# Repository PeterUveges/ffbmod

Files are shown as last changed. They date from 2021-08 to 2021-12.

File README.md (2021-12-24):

# YuSynth Fixed Filter Bank (modified)

This is a somewhat modified version of Yves Usson's [module](https://www.yusynth.net/Modular/EN/BANK/index.html) in Kosmo format. Changes are:

* Tuning.
* Addition of auxiliary PCB for board mounted slide pots and jacks (instead of Usson's panel mounted, wired rotary pots and jacks).
* Relocation of headers on main PCB to accommodate mating with sockets on panel components PCB. Ribbon cable is replaced by mated header/socket.
* Use of dual bypass caps (one from each rail to ground instead of one between the two rails).
* Omission of MOTM and MTA power headers.

## Errata

**WARNING!** On the first run PCBs (marked Aug 2021, no version number) the power connections to the ICs were reversed. To get around this, install all ICs "backwards", opposite the direction indicated on the silkscreen. The error has been corrected in the design files — by rerouting the power, not by turning the ICs — and power connections are correct on boards marked v1.0 (Oct 2021) or later. If in doubt use your multimeter before installing ICs to verify +12 V is on pin 4, -12 V is on pin 11. A good idea any time you build a module anyway, especially one with eight ICs!

## Tuning
Usson's filters are tuned to the same frequencies as in the Moog 914 module, except that for some reason he used 750 Hz instead of 700 Hz. The Moog filter frequencies are about six semitones (half an octave) apart. But note the following observation from the catalog description of the [Serge Resonant Equalizer](https://www.elby-designs.com/webtek/cgs/serge/cgs202/cgs202.htm): 

> Except for the top and bottom frequency bands, all other bands are spaced at an interval of a major seventh. This non-standard spacing avoids the very common effect of an accentuated resonance in one key, as will be the effect from graphic equalizers with octave or third-octave spacing between bands. Spacing by octaves will reinforce a regular overtone structure for one musical key, thereby producing regularly spaced formants accenting a particular tonality. The Resonant Equalizer's band spacing are much more interesting, producing formant peaks and valleys that are similar to those in acoustic instument sounds.

Following something like this idea, I have retuned Usson's module. Specifically, the first band pass is kept at 125 Hz and the other filters are tuned at six and a half semitones apart. 

For a list of the new frequencies, new capacitor values for the low pass and band pass filters, and new resistor values for the high pass filter, see [retuning.md](Docs/retuning.md).

In the tuning Usson used, all the required capacitances are non standard values, so he used pairs of standard value capacitors adding to the required value. Note that in this new tuning several of the required capacitances come out to available standard values. For those, only a single capacitor instead of two is used (saving 20 capacitors! Though this is partly offset by my use of dual bypass caps.) The unneeded capacitors are shown (marked DNF, "do not fit") in the schematic and have footprints on the PCB, in case I or anyone else ever wants to use this board for a differently-tuned version. For a build with my tuning, these footprints should be left unpopulated.

## Current draw
46 mA +12 V, 46 mA -12 V (This is what I measured; Usson says 70 mA on both rails (at ±15 V).)

## YuSynth request

Usson writes: 'All circuits, schematics, printed circuit board, panel design and associated data published on \[yusynth.net\] can be used for private use only.' I do not believe this repo violates his wishes and you are urged to respect them as well. CC0 licensing is intended to cover my modifications and original work, not to negate Usson's rights regarding his designs.

## Photos

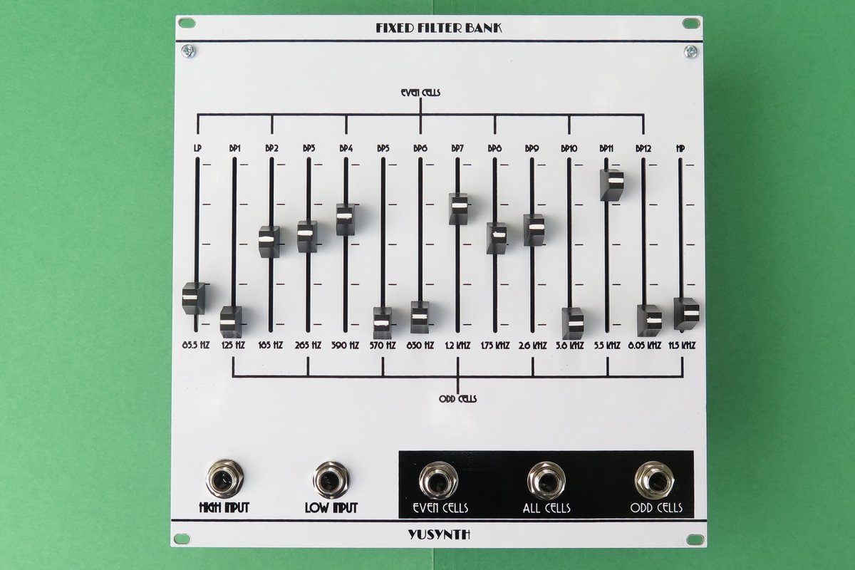
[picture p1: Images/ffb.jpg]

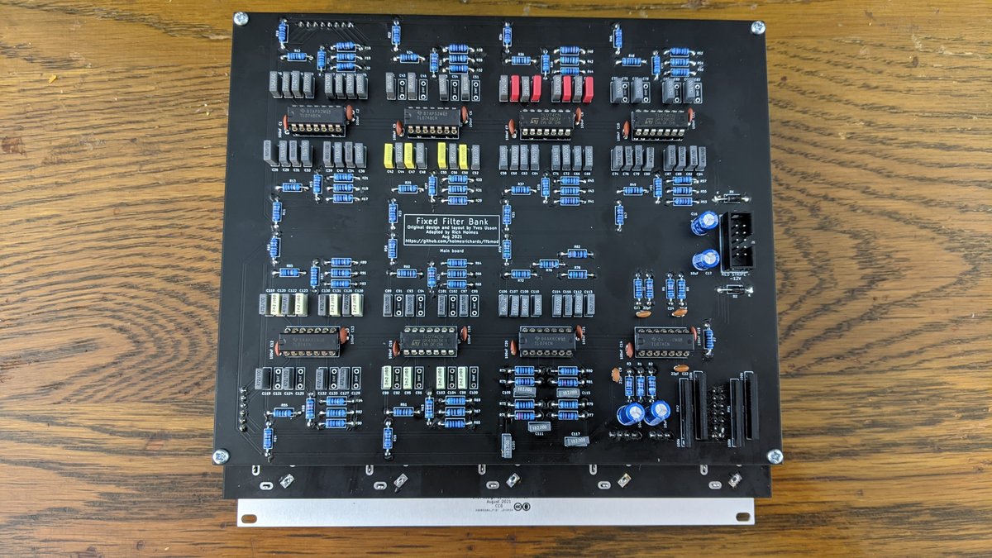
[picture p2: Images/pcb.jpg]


## Documentation:

* [Schematic](Docs/ysFFB.pdf)
* PCB layout: [front](Docs/ysFFB_layout_front.pdf), [back](Docs/ysFFB_layout_back.pdf)
* [BOM](Docs/ysFFB_bom.md)
* [Build notes](Docs/build.md)
* [Retuning](Docs/retuning.md)

## GitHub repository

* [https://github.com/holmesrichards/ffbmod](https://github.com/holmesrichards/ffbmod)

## Submodules

This repo uses submodules aoKicad and Kosmo_panel, providing libraries needed for KiCad. To clone:

```
git clone git@github.com:holmesrichards/ffb.git
git submodule init
git submodule update
```

Alternatively do

```
git clone --recurse-submodules git@github.com:holmesrichards/ffb.git
```

Or if you download the repository as a zip file, you must also click on the "aoKicad" and "Kosmo\_panel" links on the GitHub page (they'll have "@ something" after them) and download them as separate zip files which you can unzip into this repo's aoKicad and Kosmo\_panel directories.

If desired, copy the files from aoKicad and Kosmo\_panel to wherever you prefer (your KiCad user library directory, for instance, if you have one). Then in KiCad, add symbol libraries 

```
aoKicad/ao_symbols
Kosmo_panel/Kosmo
```
and footprint libraries 
```
aoKicad/ao_tht
Kosmo_panel/Kosmo_panel.
```

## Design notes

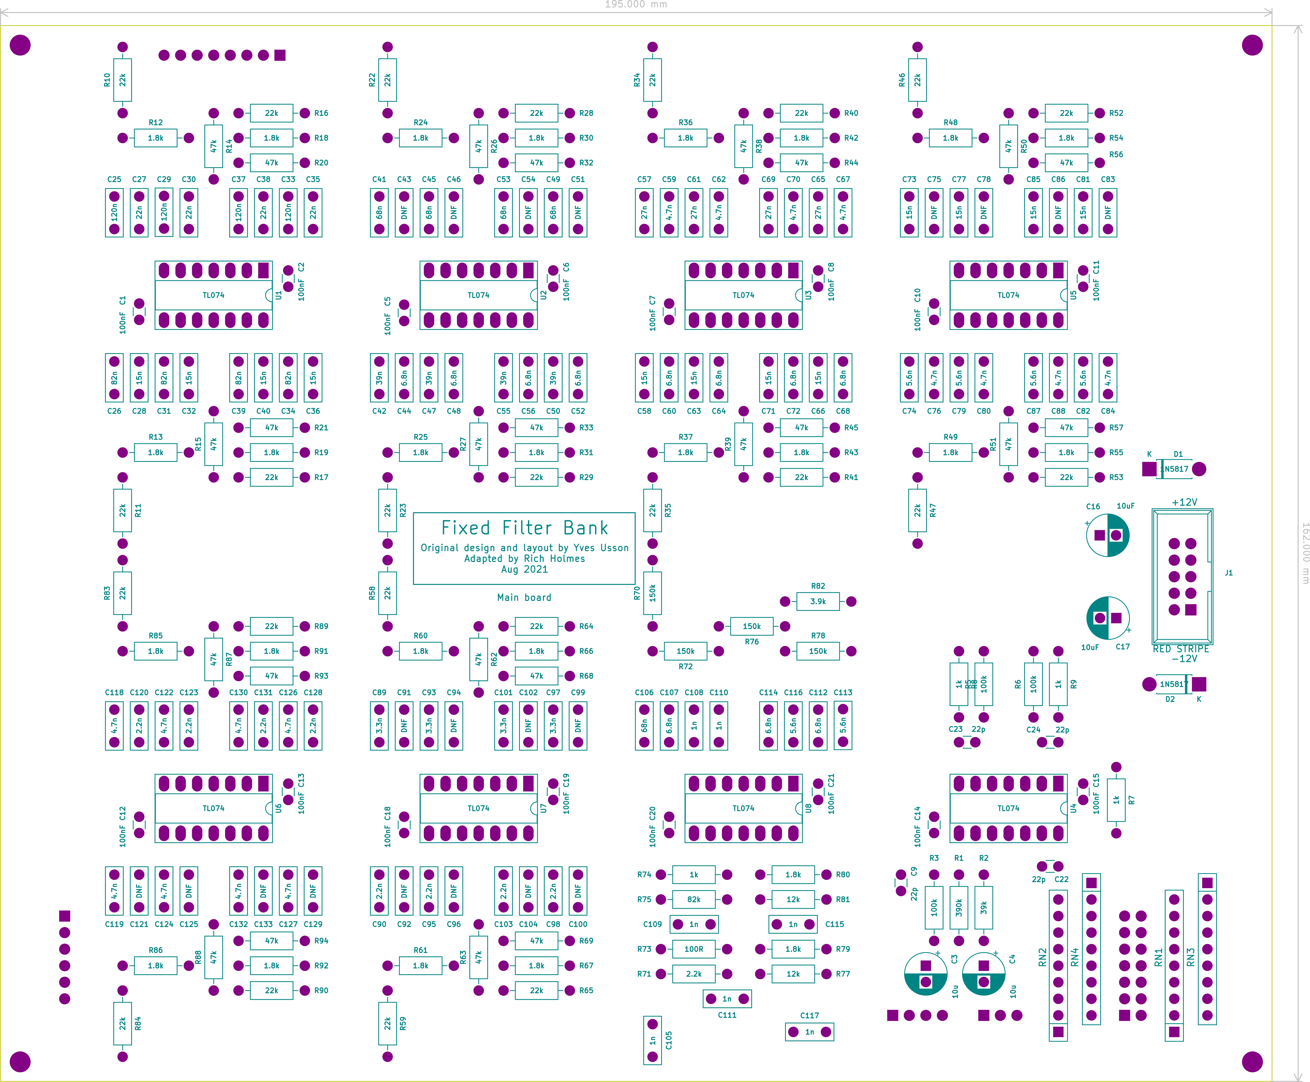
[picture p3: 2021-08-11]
Hardware/Panel/output_mb.png

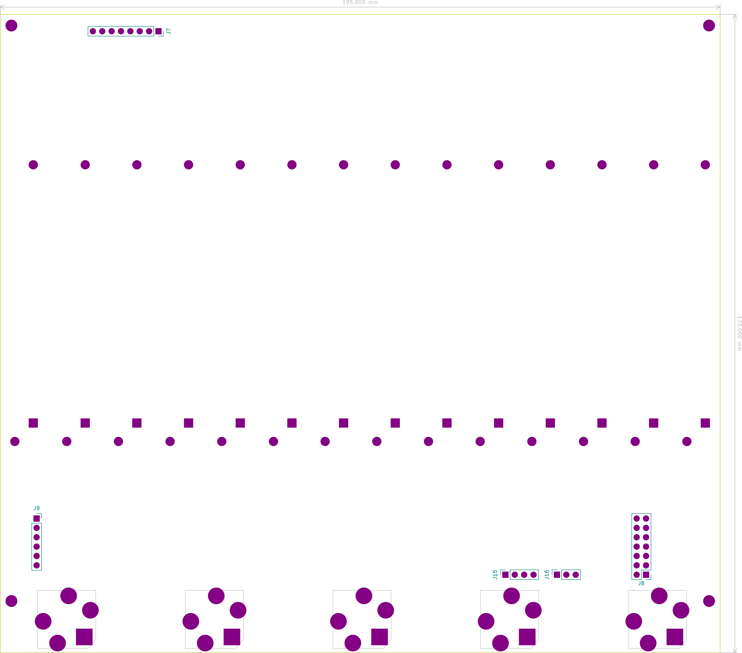
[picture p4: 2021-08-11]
Hardware/Panel/output_pb.png

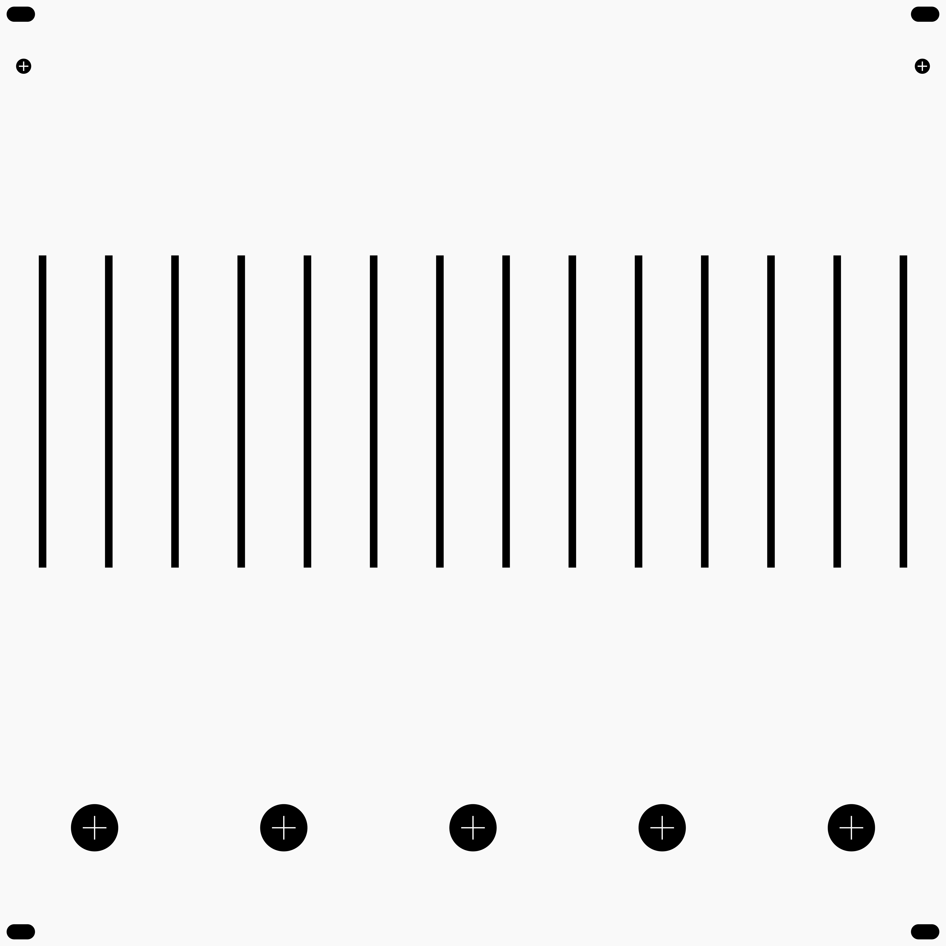
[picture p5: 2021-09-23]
Images/ysFFB-panel_slide2_holes.png

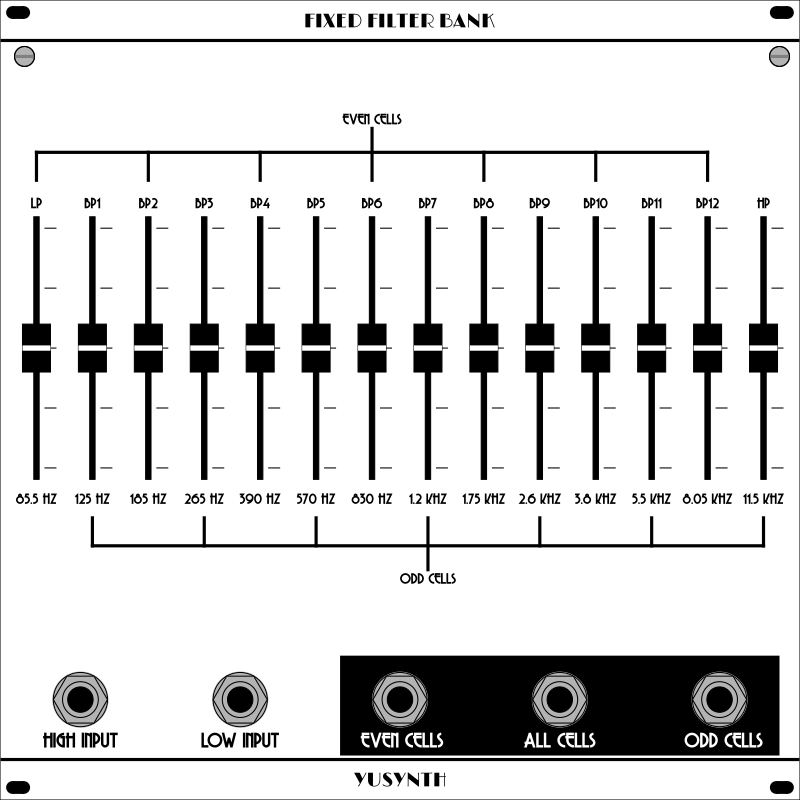
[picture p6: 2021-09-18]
Images/ysFFB-panel_slide2.png

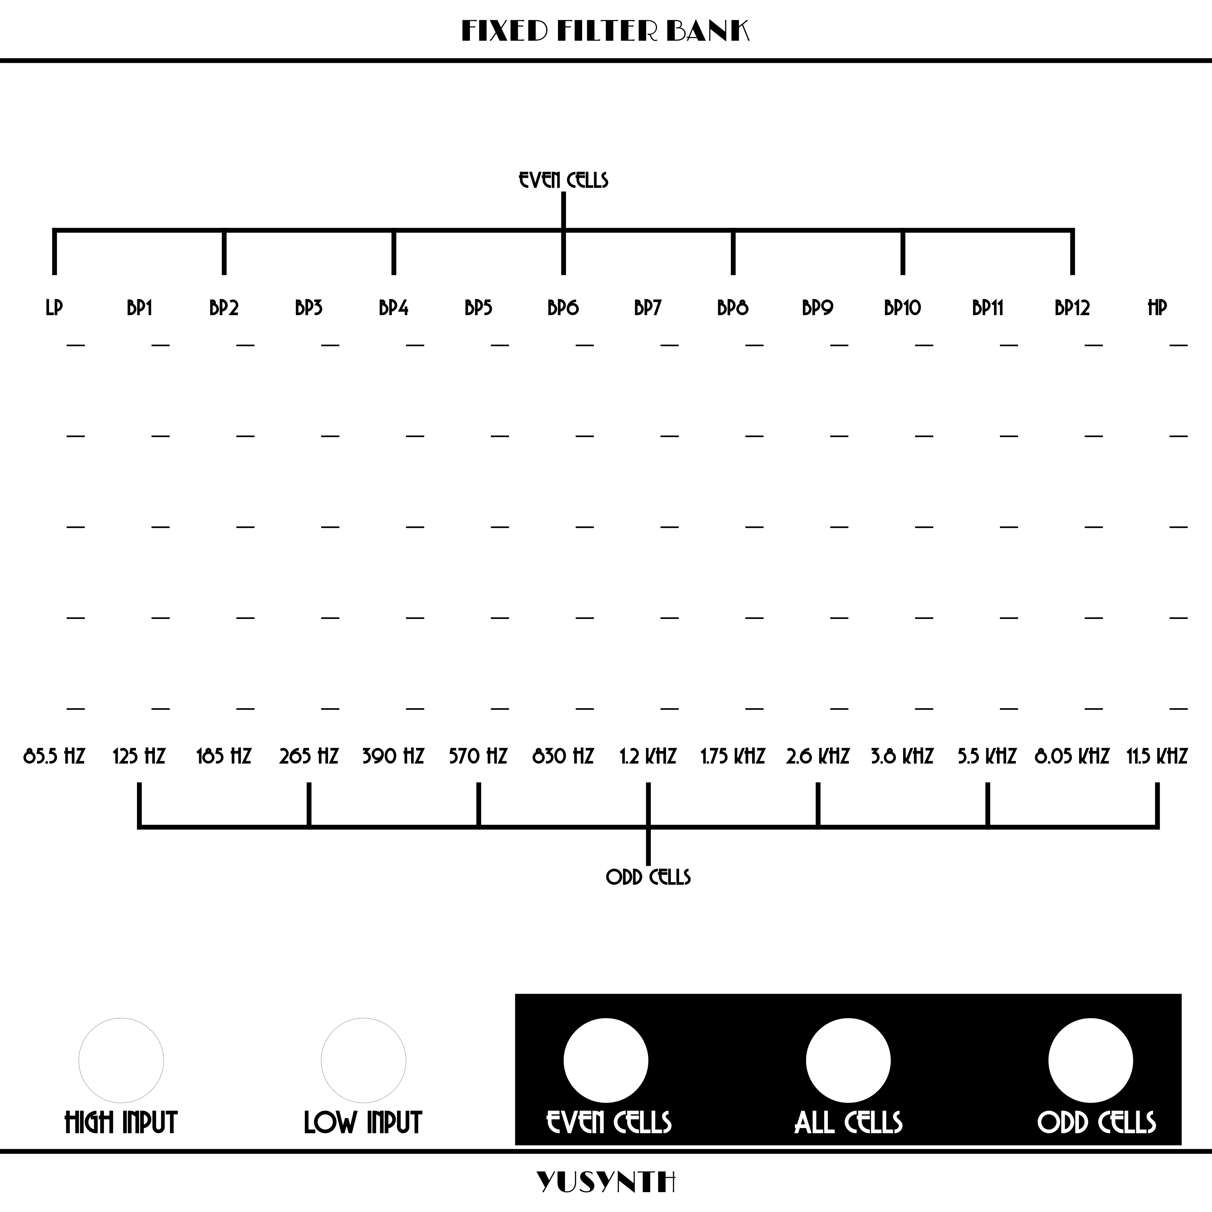
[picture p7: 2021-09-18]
Images/ysFFB-panel_slide2_art.png

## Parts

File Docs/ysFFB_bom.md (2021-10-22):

# ysFFB.sch BOM

Fri 22 Oct 2021 06:18:31 PM EDT

Generated from schematic by Eeschema 5.1.10-88a1d61d58~90~ubuntu20.04.1

**Component Count:** 270

| Refs | Qty | Component | Description | Vendor | SKU |
| ----- | --- | ---- | --- | ---- | ---- |
| C1, C2, C5, C6, C7, C8, C10, C11, C12, C13, C14, C15, C18, C19, C20, C21 | 16 | 100nF | Ceramic capacitor | Tayda | A-553 |
| C3, C4, C16, C17 | 4 | 10uF | Electrolytic capacitor | Tayda | A-4349 |
| C9, C22, C23, C24 | 4 | 22pF | Ceramic capacitor | Tayda | A-967 |
| C25, C29, C33, C37 | 4 | 120nF | Film capacitor | Tayda | A-4350 |
| C26, C31, C34, C39 | 4 | 82nF | Film capacitor | Tayda | A-279 |
| C27, C30, C35, C38 | 4 | 22nF | Film capacitor | Tayda | A-560 |
| C28, C32, C36, C40, C58, C63, C66, C71, C73, C77, C81, C85 | 12 | 15nF | Film capacitor | Tayda | A-702 |
| C41, C45, C49, C53, C106 | 5 | 68nF | Film capacitor | Tayda | A-707 |
| C42, C47, C50, C55 | 4 | 39nF | Film capacitor | Tayda | A-711 |
| C44, C48, C52, C56, C60, C64, C68, C72, C107, C112, C114 | 11 | 6.8nF | Film capacitor | Tayda | A-421 |
| C57, C61, C65, C69 | 4 | 27nF | Film capacitor | Tayda | A-562 |
| C59, C62, C67, C70, C76, C80, C84, C88, C118, C119, C122, C124, C126, C127, C130, C132 | 16 | 4.7nF | Film capacitor | Tayda | A-413 |
| C74, C79, C82, C87, C113, C116 | 6 | 5.6nF | Film capacitor | Tayda | A-423 |
| C89, C93, C97, C101 | 4 | 3.3nF | Film capacitor | Tayda | A-414 |
| C90, C95, C98, C103, C120, C123, C128, C131 | 8 | 2.2nF | Film capacitor | Tayda | A-558 |
| C105, C108, C109, C110, C111, C115, C117 | 7 | 1nF | Film capacitor | Tayda | A-557 |
| D1, D2 | 2 | 1N5817 | Schottky diode | Tayda | A-159 |
| J1 | 1 | Synth_power_2x5 | Shrouded IDC header 2.54 mm 2x5 | Tayda | A-2939 |
| J2 | 1 | Conn_01x08 | Pin header 2.54 mm 1x8 | Tayda | A-197 |
| J3 | 1 | Conn_01x06 | Pin header 2.54 mm 1x6 | Tayda | A-197 |
| J4 | 1 | Conn_01x04 | Pin header 2.54 mm 1x4 | Tayda | A-197 |
| J5 | 1 | Conn_02x07_Odd_Even | Pin header 2.54 mm 2x7 | Tayda | A-198 |
| J6 | 1 | Conn_01x03 | Pin header 2.54 mm 1x3 | Tayda | A-197 |
| J7 | 1 | Conn_01x08 | Pin socket 2.54 mm 1x8 | Tayda | A-196 |
| J8 | 1 | Conn_02x07_Odd_Even | Pin socket 2.54 mm 2x7 | Tayda | A-1696 |
| J9 | 1 | Conn_01x06 | Pin socket 2.54 mm 1x6 | Tayda | A-196 |
| J10, J11, J12, J13, J14 | 5 | AudioJack2 | Audio Jack, 2 Poles (Mono / TS) | Tayda | A-1121 |
| J15 | 1 | Conn_01x04 | Pin socket 2.54 mm 1x4 | Tayda | A-196 |
| J16 | 1 | Conn_01x03 | Pin socket 2.54 mm 1x3 | Tayda | A-196 |
| R1 | 1 | 390k | Resistor |  |  |
| R2 | 1 | 39k | Resistor |  |  |
| R3, R5, R6 | 3 | 100k | Resistor |  |  |
| R7, R8, R9, R74 | 4 | 1k | Resistor |  |  |
| R10, R11, R16, R17, R22, R23, R28, R29, R34, R35, R40, R41, R46, R47, R52, R53, R58, R59, R64, R65, R83, R84, R89, R90 | 24 | 22k | Resistor |  |  |
| R12, R13, R18, R19, R24, R25, R30, R31, R36, R37, R42, R43, R48, R49, R54, R55, R60, R61, R66, R67, R79, R80, R85, R86, R91, R92 | 26 | 1.8k | Resistor |  |  |
| R14, R15, R20, R21, R26, R27, R32, R33, R38, R39, R44, R45, R50, R51, R56, R57, R62, R63, R68, R69, R87, R88, R93, R94 | 24 | 47k | Resistor |  |  |
| R70, R72, R76, R78 | 4 | 150k | Resistor |  |  |
| R71 | 1 | 2.2k | Resistor |  |  |
| R73 | 1 | 100R | Resistor |  |  |
| R75 | 1 | 82k | Resistor |  |  |
| R77, R81 | 2 | 12k | Resistor |  |  |
| R82 | 1 | 3.9k | Resistor |  |  |
| RN1, RN2, RN3, RN4 | 4 | 100k | 8 resistor network, star topology, bussed resistors | Digi-Key | 4309R-101-104LF |
| RV1, RV2, RV3, RV4, RV5, RV6, RV7, RV8, RV9, RV10, RV11, RV12, RV13, RV14 | 14 | A10k | 60 mm slide potentiometer | Tayda | A-1617 |
| U1, U2, U3, U4, U5, U6, U7, U8 | 8 | TL074 | Quad operational amplifier, DIP-14 | Tayda | A-1138 |
| | 8 | | DIP socket 14 pin | Tayda | A-004 |
| | 6 | | M3 screw 6 mm | Tayda | A-1250 |
| | 2 | | M3 washer | Tayda | A-4389 |
| | 2 | | M3 spacer MF 22 mm | Tayda | A-1285 |
| | 4 | | M3 spacer FF 10 mm | Tayda | A-1232 |
| | 14 | | Slide pot shaft cap | AliExpress | |
    
The following references have footprints but are not populated:
C43, C46, C51, C54, C75, C78, C83, C86, C91, C92, C94, C96, C99, C100, C102, C104, C121, C125, C129, C133

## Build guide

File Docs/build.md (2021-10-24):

# Fixed filter bank build notes

This is a pretty massive module, with a 20 by 20 cm front panel, 94 fixed resistors (not counting four resistor arrays), 14 slide pots, 113 capacitors, and 8 quad op amps. But building it is very straightforward. A lot of soldering but not a lot of complications.

To repeat from the README file:

**WARNING!** On the first run PCBs (marked Aug 2021, no version number) the power connections to the ICs were reversed. To get around this, install all ICs "backwards", opposite the direction indicated on the silkscreen. The error has been corrected in the design files — by rerouting the power, not by turning the ICs — and power connections are correct on boards marked v1.0 (Oct 2021) or later. If in doubt use your multimeter before installing ICs to verify +12 V is on pin 4, -12 V is on pin 11. A good idea any time you build a module anyway, especially one with eight ICs!

Each filter has its own region on the PCB, plus a region for the input and output sections. I built mine incrementally. I did the input and output sections and one of the bandpass filters first, and tested those. Then I added the low and high pass filters, and tested again. Then I added the remaining 11 bandpass filters.

This was the first time I used SIP resistor arrays. These contain eight resistors all connected at one end to one terminal and at the other end to eight other individual terminals. The common terminal is the one on the left when the printing on the SIP is facing you, and it goes in the hole with the square pad. (Note two arrays are oriented opposite the other two.)

I recommend soldering at least the 2x7 pin header on the main PCB before the resistor arrays. But you might as well do them all. Put the pin headers and sockets together and sandwich them between the PCBs before soldering them. They all go on the sides opposite the other components. I found it easier to do the three larger headers/sockets first, then add the two smaller ones.

As usual, use the front panel to line up the pots and jacks before soldering them in place.

To assemble mechanically: Screw two 22 mm male-female spacers to the mounting holes on the front panel. Screw two 10 mm female-female spacers, with a washer added, to the bottom mounting holes on the panel components board. Secure the panel components PCB to the front panel using the jacks and by screwing two more 10 mm spacers, again with a washer added, onto the 22 mm spacers. Plug the main PCB headers into the panel components PCB sockets and secure the main PCB with four screws into the 10 mm spacers.

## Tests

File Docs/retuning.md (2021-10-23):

# YuSynth Fixed Filter Bank retuning

New frequencies and component values, computed using the formulas in Usson's writeup, are shown below. I wrote a Python script to aid in this which you can find in the Software folder. All the capacitor values are available for polyester film caps from Tayda as of April 2021. 

Note that some capacitor references are not used; the footprints are on the PCB but should be left unpopulated.

These tables were transcribed manually from the schematics. If you find any discrepancies, believe the schematics.

### Low pass
| Freq | Ref | Value | Ref | Value |
| ---- | --- | ----- | --- | ----- |
| 85.5 Hz | C106 | 68 nF | C107 | 6.8 nF |
| | C108 | 1 nF | C114 | 1 nF |
| | C112 C114 | 6.8 nF	| C113 C116 | 5.6 nF |

### Band pass
| Number | Freq | Ref | Value | Ref | Value |
| --- | ---- | --- | ----- | --- | ----- |
|1| 125 Hz | C25 C29 C33 C37 | 120 nF | C27 C30 C35 C38 | 22 nF |
|2| 185 Hz | C26 C31 C34 C39 | 82 nF | C28 C32 C36 C40 | 15 nF |
|3| 265 Hz | C41 C45  C49  C53  | 68 nF | C43 C36  C51  C54  | [unused] |
|4| 390 Hz | C42  C47  C50  C55  | 39 nF | C44  C48  C52  C56  | 6.8 nF |
|5| 570 Hz | C57  C61  C65  C69  | 27 nF | C59  C62  C67  C70  | 4.7 nF |
|6| 830 Hz | C58  C63  C66  C71  | 15 nF | C60  C64  C68  C72  | 6.8 nF |
|7| 1200 Hz | C73  C77  C81  C85  | 15 nF | C75  C78  C83  C86  | [unused] |
|8| 1750 Hz | C74  C79  C82  C87  | 5.6 nF | C76  C80  C84  C88  | 4.7 nF |
|9| 2600 Hz | C118 C122 C126 C130 | 4.7 nF | C120 C123 C128 C131 | 2.2 nF |
|10| 3800 Hz | C119 C124 C127 C132 | 4.7 nF | C121 C125 C129 C133 | [unused] |
|11| 5500 Hz | C89  C93  C97  C101 | 3.3 nF | C91  C94  C99  C104 | [unused] |
|12| 8050 Hz | C90  C95  C96  C103 | 2.2 nF | C92  C96  C100 C104 | [unused] |

### High pass
| Freq | Ref | Value | Ref | Value |
| ---- | --- | ----- | --- | ----- |
| 11500 Hz | R71  | 2.2 kΩ | R73  | 100 Ω |
|  | R75  | 82 kΩ | R74  | 1 kΩ |
|  | R77  R81  | 12 kΩ | R79  R80  | 1.8 kΩ |

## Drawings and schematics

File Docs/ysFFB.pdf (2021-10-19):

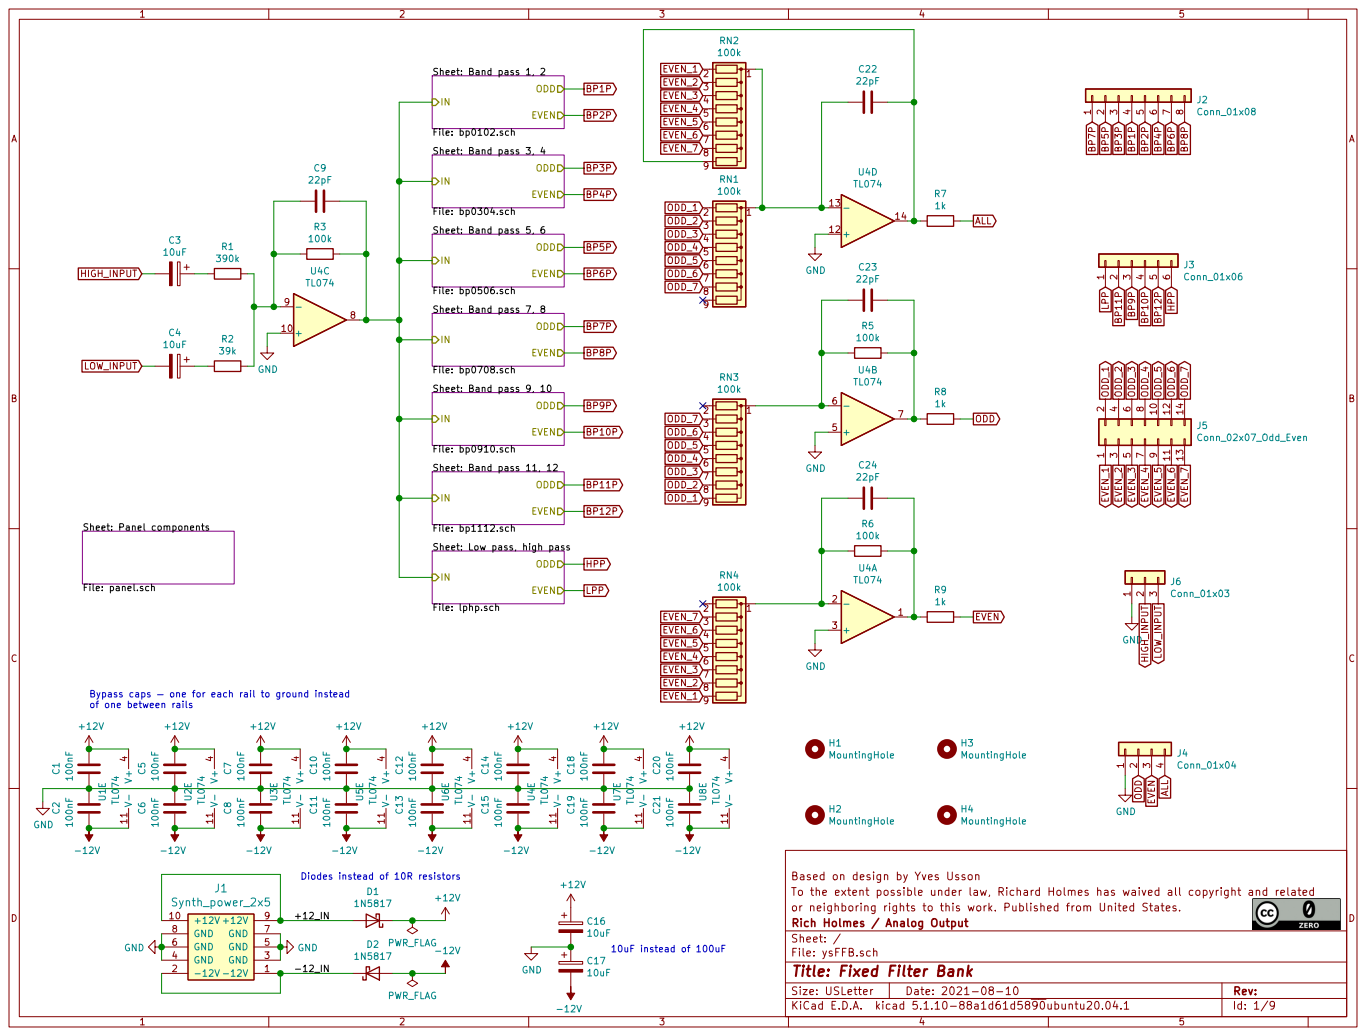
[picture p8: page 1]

Sheet: Low pass, high pass

10uF instead of 100uF Diodes instead of 10R resistors Bypass caps one for each rail to ground instead
of one between rails

Based on design by Yves Usson
To the extent possible under law, Richard Holmes has waived all copyright and related
or neighboring rights to this work. Published from United States.
File: ysFFB.sch Sheet: / Rich Holmes / Analog Output

Id: 1/9 Title: Fixed Filter Bank

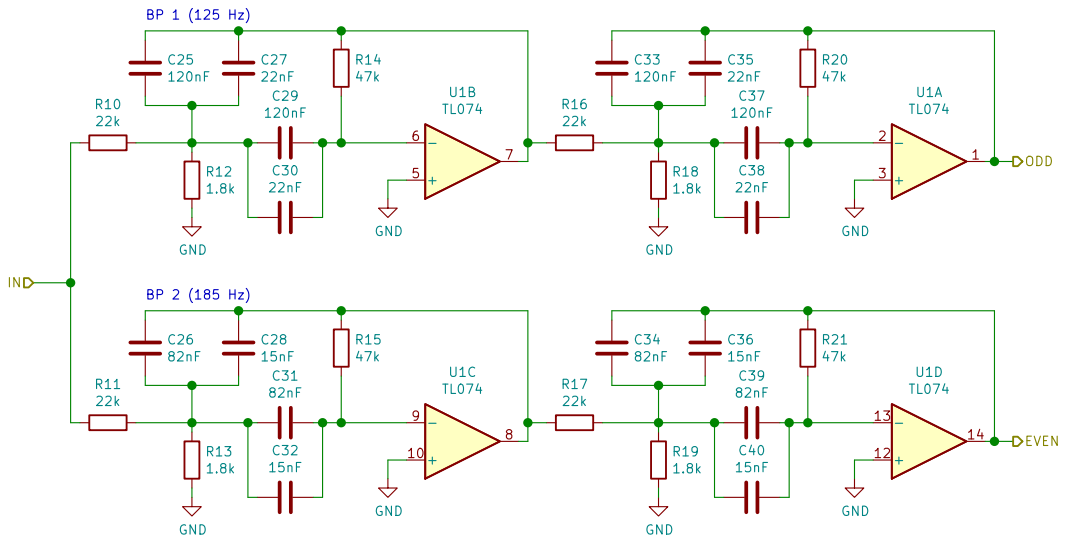
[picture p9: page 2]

Based on design by Yves Usson
To the extent possible under law, Richard Holmes has waived all copyright and related
or neighboring rights to this work. Published from United States.
Rich Holmes / Analog Output
Sheet: /Band pass 1, 2/
File: bp0102.sch
Id: 2/9 Title: Fixed Filter Bank

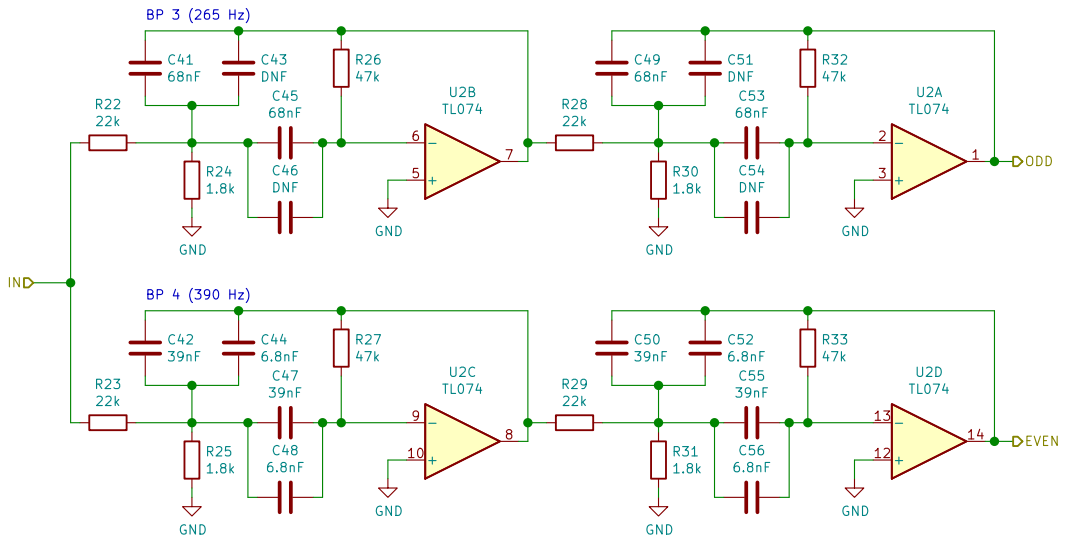
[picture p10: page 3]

Based on design by Yves Usson R25

To the extent possible under law, Richard Holmes has waived all copyright and related
or neighboring rights to this work. Published from United States.
Rich Holmes / Analog Output
Sheet: /Band pass 3, 4/
File: bp0304.sch
Id: 3/9 Title: Fixed Filter Bank

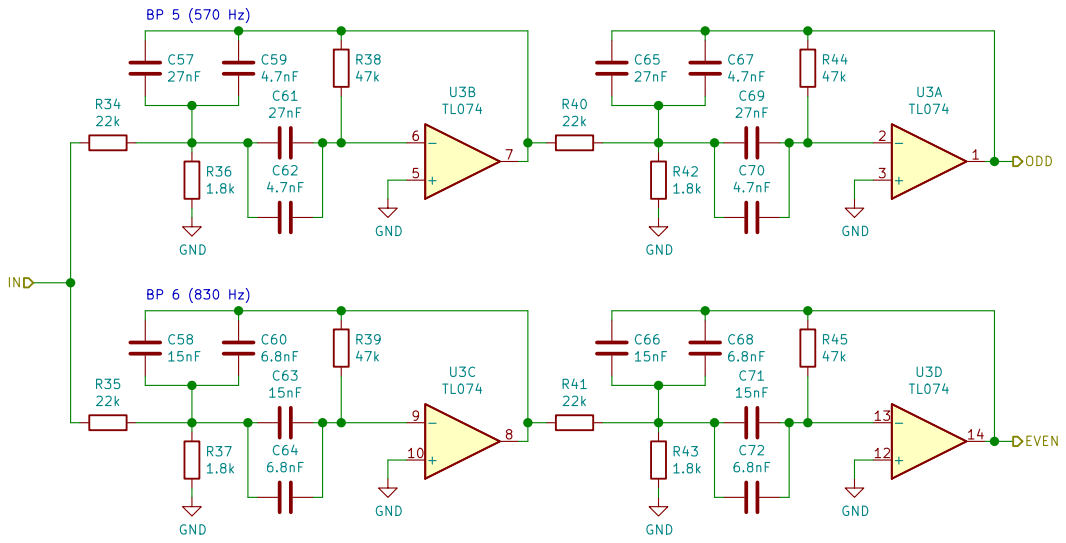
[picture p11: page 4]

Based on design by Yves Usson
To the extent possible under law, Richard Holmes has waived all copyright and related
or neighboring rights to this work. Published from United States.
Rich Holmes / Analog Output
Sheet: /Band pass 5, 6/
File: bp0506.sch
Id: 4/9 Title: Fixed Filter Bank

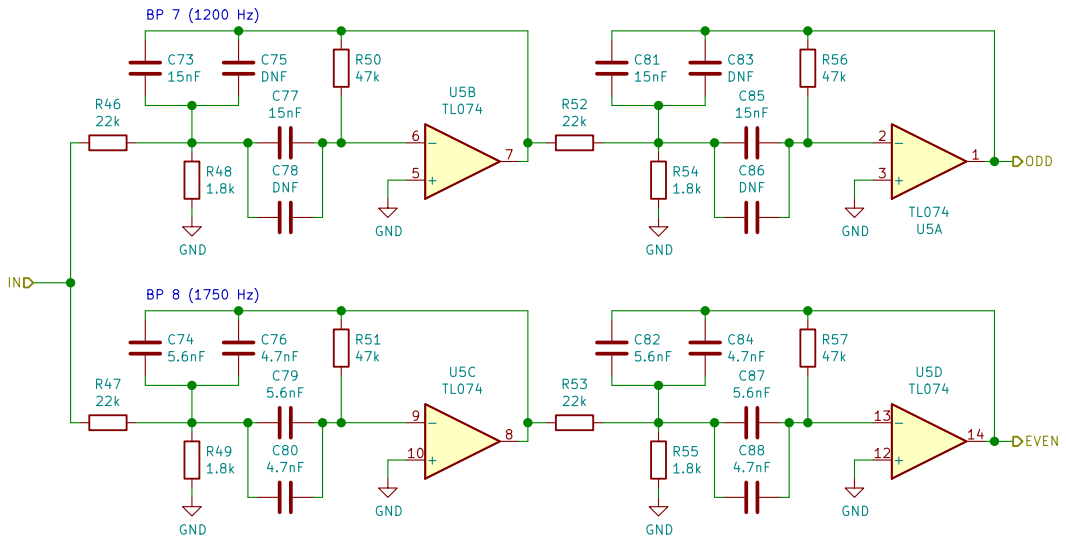
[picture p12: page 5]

Based on design by Yves Usson R49

To the extent possible under law, Richard Holmes has waived all copyright and related
or neighboring rights to this work. Published from United States.
Rich Holmes / Analog Output
Sheet: /Band pass 7, 8/
File: bp0708.sch
Id: 5/9 Title: Fixed Filter Bank

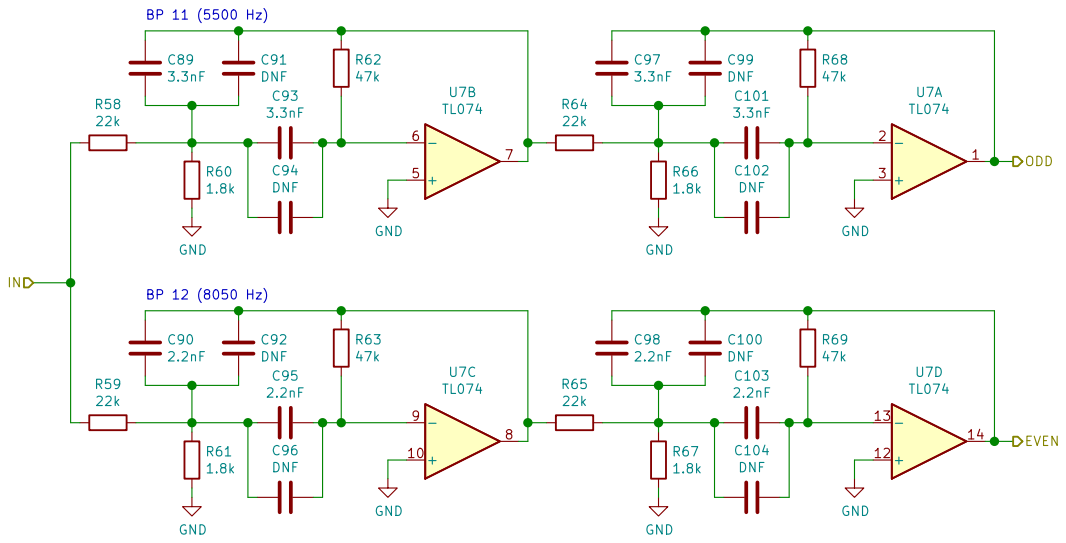
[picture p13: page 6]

Based on design by Yves Usson R61

To the extent possible under law, Richard Holmes has waived all copyright and related
or neighboring rights to this work. Published from United States.
Rich Holmes / Analog Output
Sheet: /Band pass 11, 12/
File: bp1112.sch
Id: 6/9 Title: Fixed Filter Bank

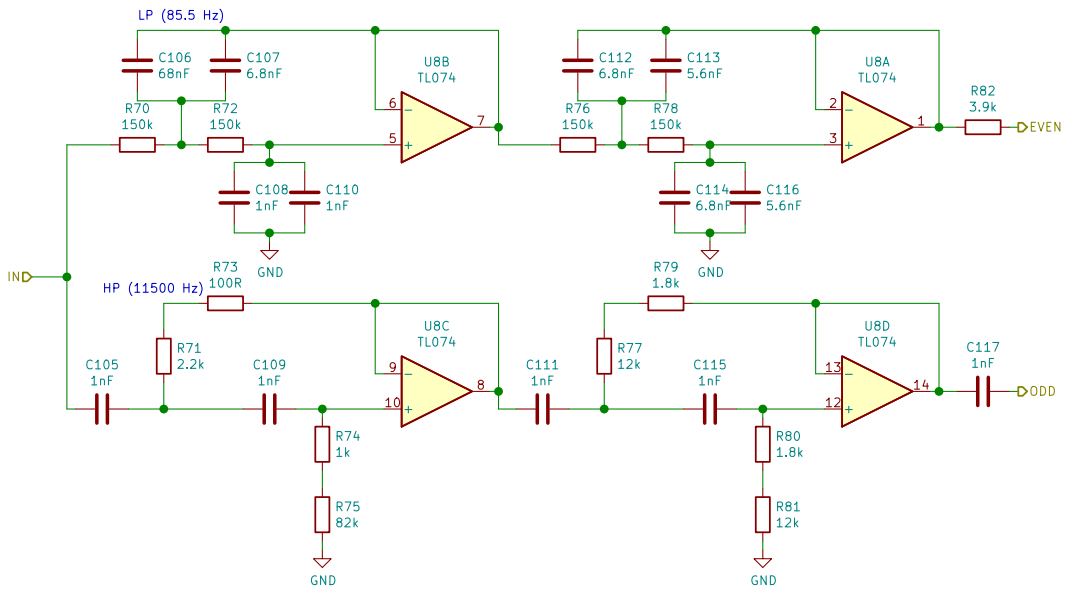
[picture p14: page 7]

Based on design by Yves Usson R75

To the extent possible under law, Richard Holmes has waived all copyright and related
or neighboring rights to this work. Published from United States.
Rich Holmes / Analog Output
Sheet: /Low pass, high pass/
File: lphp.sch
Id: 7/9 Title: Fixed Filter Bank

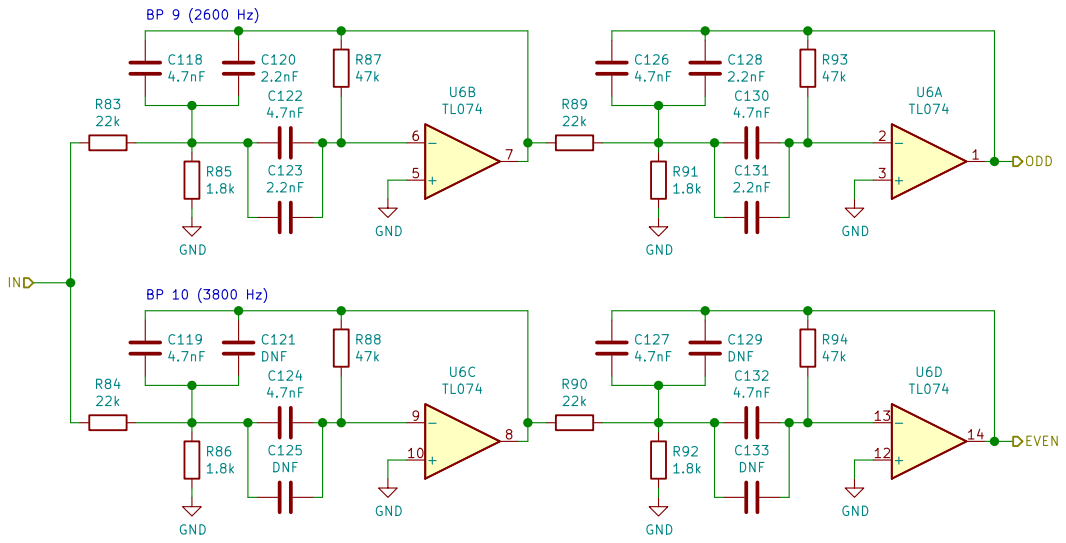
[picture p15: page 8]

Based on design by Yves Usson
To the extent possible under law, Richard Holmes has waived all copyright and related
or neighboring rights to this work. Published from United States.
Rich Holmes / Analog Output
Sheet: /Band pass 9, 10/
File: bp0910.sch
Id: 8/9 Title: Fixed Filter Bank

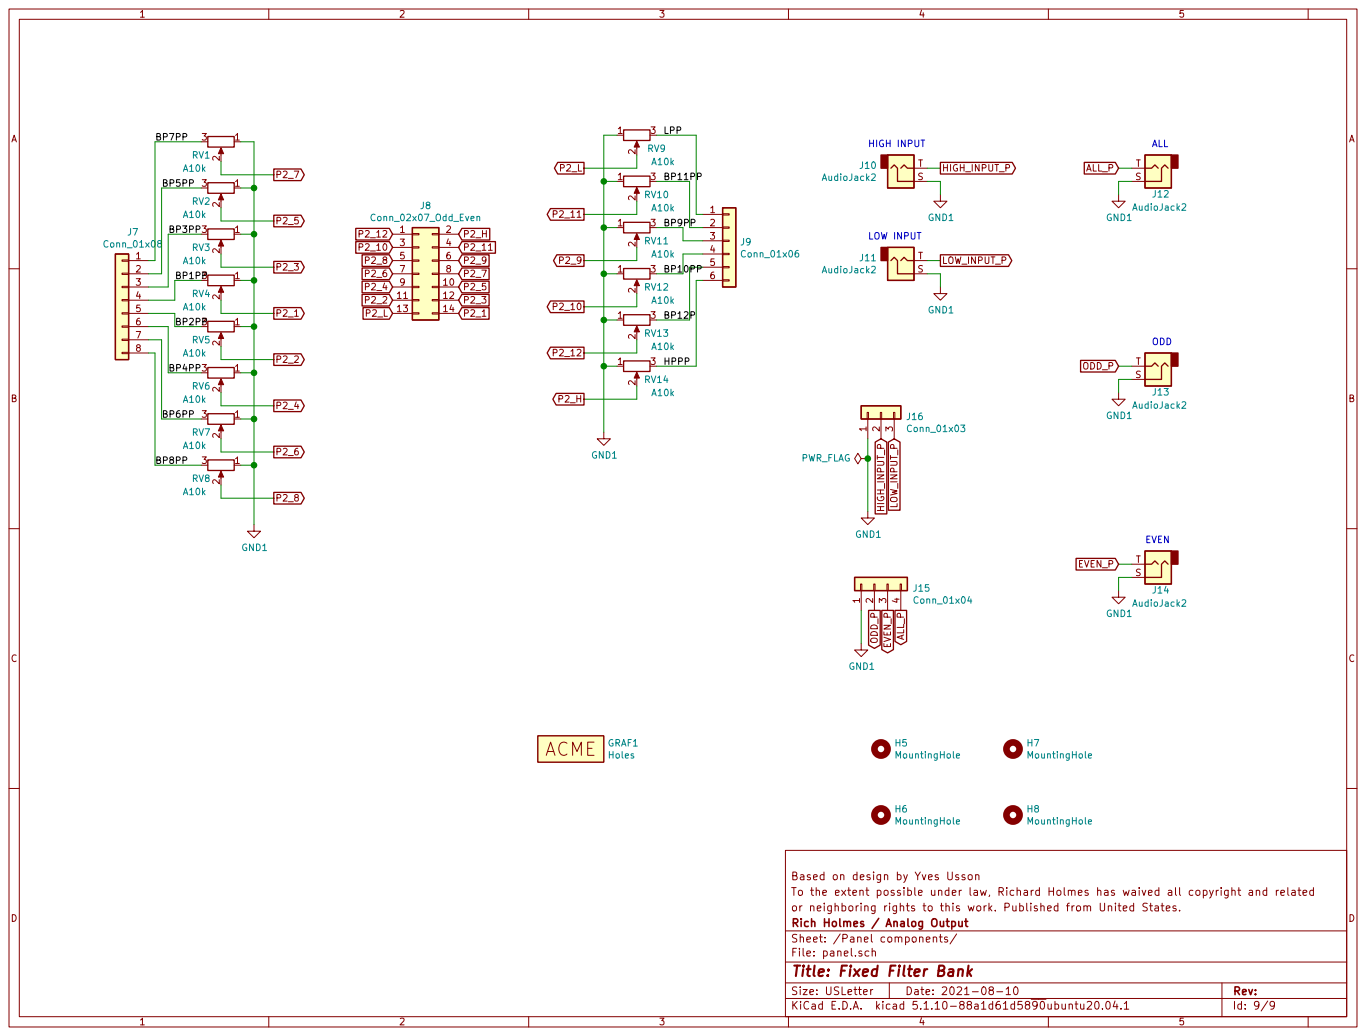
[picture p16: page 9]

To the extent possible under law, Richard Holmes has waived all copyright and related
or neighboring rights to this work. Published from United States.
Rich Holmes / Analog Output
Sheet: /Panel components/
File: panel.sch
Id: 9/9 Title: Fixed Filter Bank

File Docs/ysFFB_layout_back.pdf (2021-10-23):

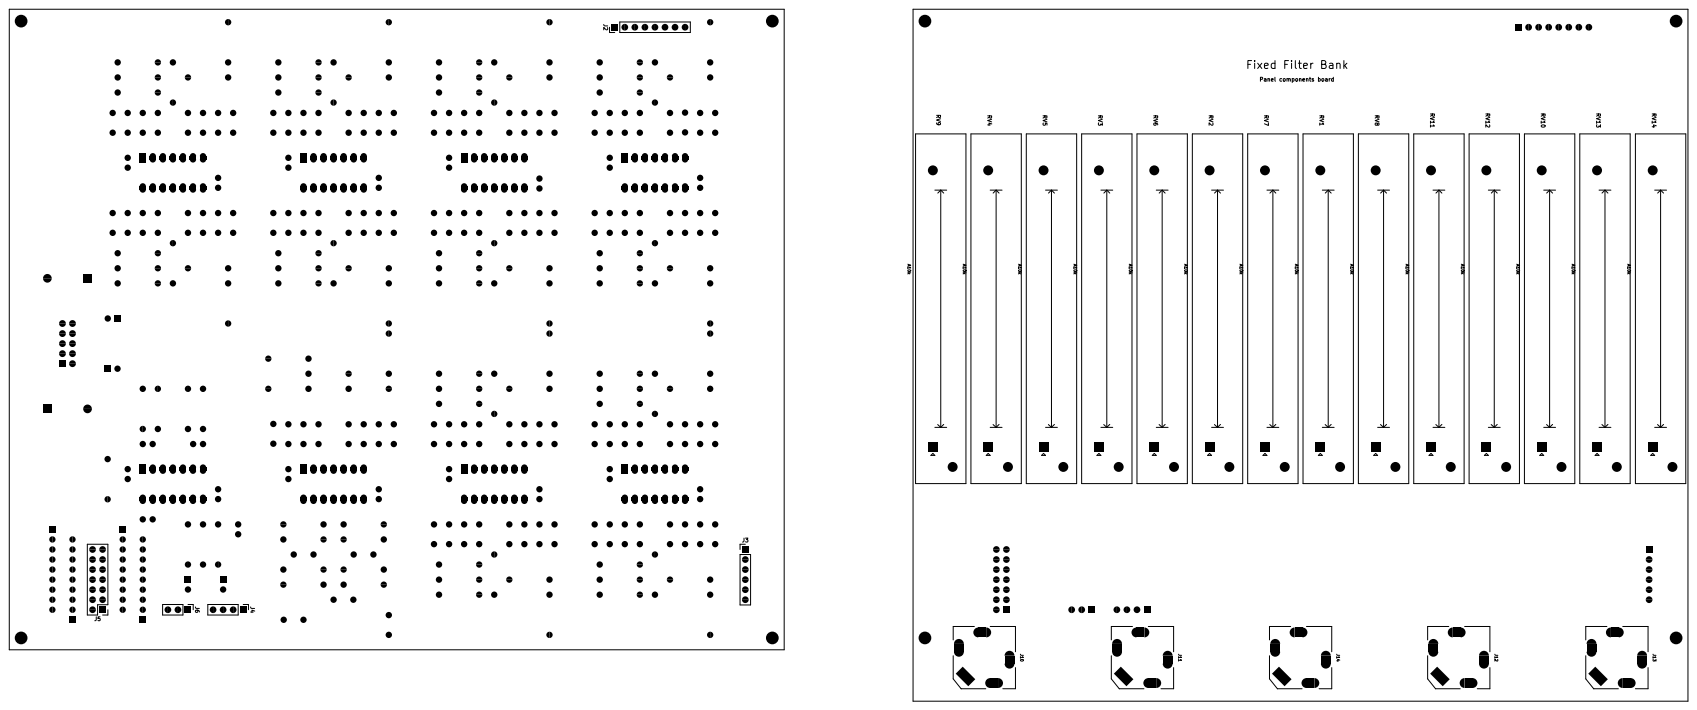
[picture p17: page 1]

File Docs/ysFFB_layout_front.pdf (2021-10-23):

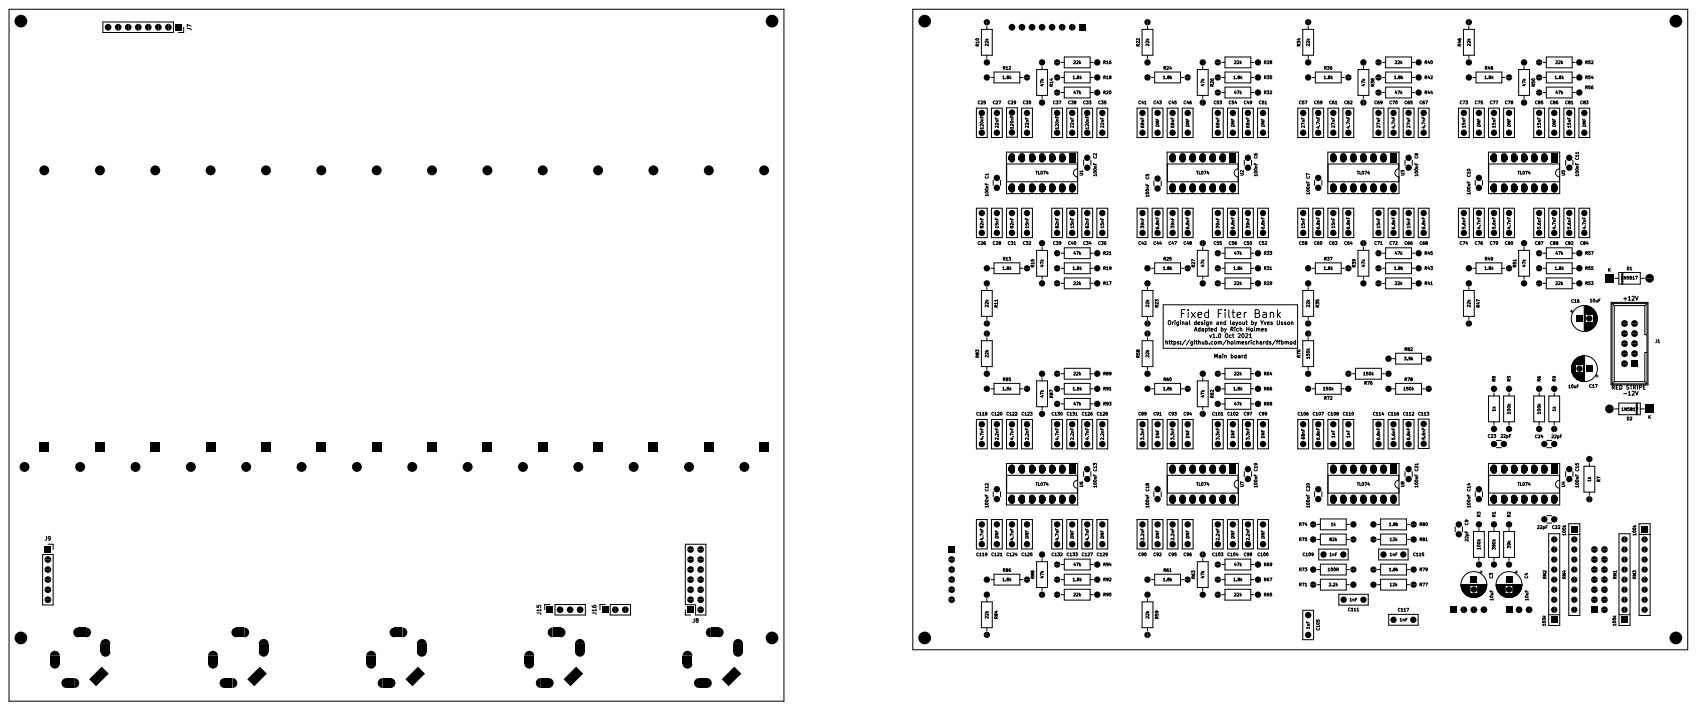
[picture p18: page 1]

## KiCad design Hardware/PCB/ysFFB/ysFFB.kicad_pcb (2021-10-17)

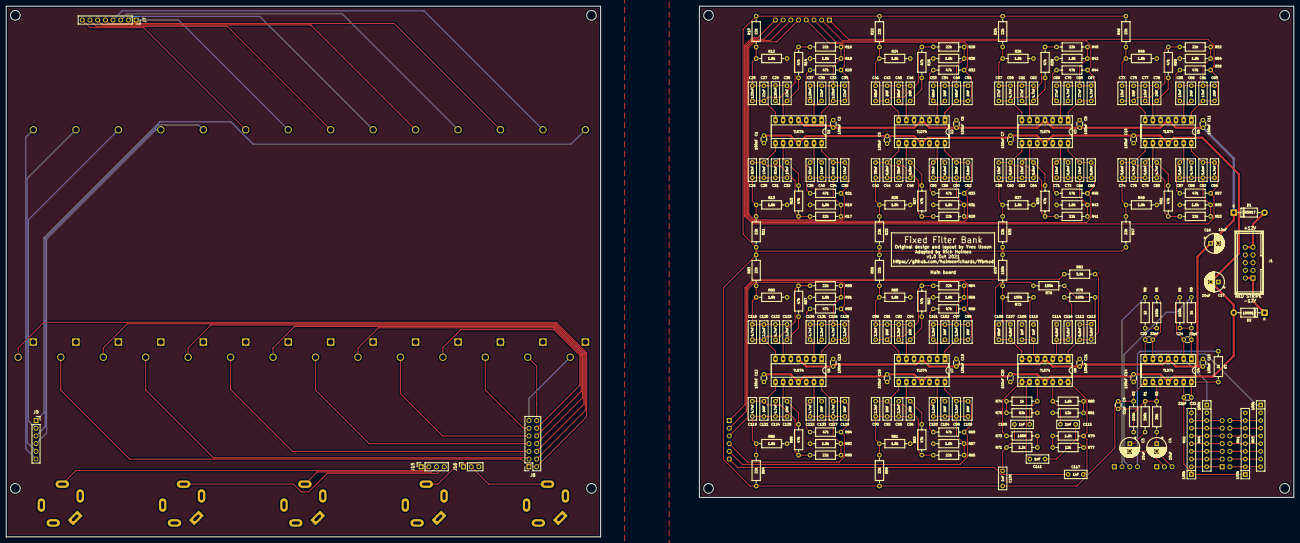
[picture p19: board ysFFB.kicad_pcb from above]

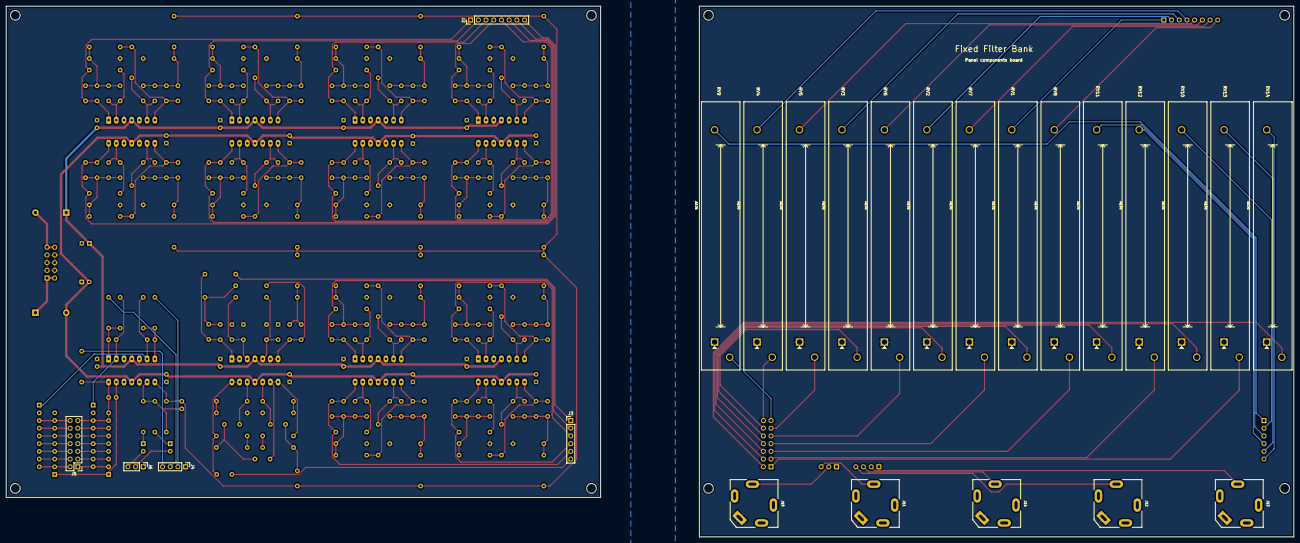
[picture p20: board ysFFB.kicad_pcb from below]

Board: 2 copper layers, 196.0 x 162.0 mm, 279 parts (24 on the bottom side), 158 nets.

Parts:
C1, C2, C5, C6, C7, C8, C10, C11, C12, C13, C14, C15, C18, C19, C20, C21: 100nF; C_Disc_D3.0mm_W1.6mm_P2.50mm
C3, C4, C16, C17: 10uF; CP_Radial_D6.3mm_P2.50mm
C9, C22, C23, C24: 22pF; C_Disc_D3.0mm_W1.6mm_P2.50mm
C25, C29, C33, C37: 120nF; C_Rect_L7.2mm_W2.5mm_P5.00mm_FKS2_FKP2_MKS2_MKP2
C26, C31, C34, C39: 82nF; C_Rect_L7.2mm_W2.5mm_P5.00mm_FKS2_FKP2_MKS2_MKP2
C27, C30, C35, C38: 22nF; C_Rect_L7.2mm_W2.5mm_P5.00mm_FKS2_FKP2_MKS2_MKP2
C28, C32, C36, C40, C58, C63, C66, C71, C73, C77, C81, C85: 15nF; C_Rect_L7.2mm_W2.5mm_P5.00mm_FKS2_FKP2_MKS2_MKP2
C41, C45, C49, C53, C106: 68nF; C_Rect_L7.2mm_W2.5mm_P5.00mm_FKS2_FKP2_MKS2_MKP2
C42, C47, C50, C55: 39nF; C_Rect_L7.2mm_W2.5mm_P5.00mm_FKS2_FKP2_MKS2_MKP2
C43, C46, C51, C54, C75, C78, C83, C86, C91, C92, C94, C96, C99, C100, C102, C104, C121, C125, C129, C133: DNF; C_DNF_Rect_L7.2mm_W2.5mm_P5.00mm_FKS2_FKP2_MKS2_MKP2
C44, C48, C52, C56, C60, C64, C68, C72, C107, C112, C114: 6.8nF; C_Rect_L7.2mm_W2.5mm_P5.00mm_FKS2_FKP2_MKS2_MKP2
C57, C61, C65, C69: 27nF; C_Rect_L7.2mm_W2.5mm_P5.00mm_FKS2_FKP2_MKS2_MKP2
C59, C62, C67, C70, C76, C80, C84, C88, C118, C119, C122, C124, C126, C127, C130, C132: 4.7nF; C_Rect_L7.2mm_W2.5mm_P5.00mm_FKS2_FKP2_MKS2_MKP2
C74, C79, C82, C87, C113, C116: 5.6nF; C_Rect_L7.2mm_W2.5mm_P5.00mm_FKS2_FKP2_MKS2_MKP2
C89, C93, C97, C101: 3.3nF; C_Rect_L7.2mm_W2.5mm_P5.00mm_FKS2_FKP2_MKS2_MKP2
C90, C95, C98, C103, C120, C123, C128, C131: 2.2nF; C_Rect_L7.2mm_W2.5mm_P5.00mm_FKS2_FKP2_MKS2_MKP2
C105, C108, C109, C110, C111, C115, C117: 1nF; C_Rect_L7.2mm_W2.5mm_P5.00mm_FKS2_FKP2_MKS2_MKP2
D1, D2: 1N5817; D_DO-41_SOD81_P10.16mm_Horizontal
GRAF1: Holes; ysFFB-aux-slide2_holes
H1, H2, H3, H4, H5, H6, H7, H8: MountingHole; MountingHole_3.2mm_M3
J1: Synth_power_2x5; Power_Header
J2: Conn_01x08; PinHeader_1x08_P2.54mm_Vertical
J3: Conn_01x06; PinHeader_1x06_P2.54mm_Vertical
J4: Conn_01x04; PinHeader_1x04_P2.54mm_Vertical
J5: Conn_02x07_Odd_Even; PinHeader_2x07_P2.54mm_Vertical
J6: Conn_01x03; PinHeader_1x03_P2.54mm_Vertical
J7: Conn_01x08; PinSocket_1x08_P2.54mm_Vertical
J8: Conn_02x07_Odd_Even; PinSocket_2x07_P2.54mm_Vertical
J9: Conn_01x06; PinSocket_1x06_P2.54mm_Vertical
J10, J11, J12, J13, J14: AudioJack2; Jack_6.35mm_PJ_629HAN_slots
J15: Conn_01x04; PinSocket_1x04_P2.54mm_Vertical
J16: Conn_01x03; PinSocket_1x03_P2.54mm_Vertical
R1: 390k; R_Axial_DIN0207_L6.3mm_D2.5mm_P10.16mm_Horizontal
R2: 39k; R_Axial_DIN0207_L6.3mm_D2.5mm_P10.16mm_Horizontal
R3, R5, R6: 100k; R_Axial_DIN0207_L6.3mm_D2.5mm_P10.16mm_Horizontal
R7, R8, R9, R74: 1k; R_Axial_DIN0207_L6.3mm_D2.5mm_P10.16mm_Horizontal
R10, R11, R16, R17, R22, R23, R28, R29, R34, R35, R40, R41, R46, R47, R52, R53, R58, R59, R64, R65, R83, R84, R89, R90: 22k; R_Axial_DIN0207_L6.3mm_D2.5mm_P10.16mm_Horizontal
R12, R13, R18, R19, R24, R25, R30, R31, R36, R37, R42, R43, R48, R49, R54, R55, R60, R61, R66, R67, R79, R80, R85, R86, R91, R92: 1.8k; R_Axial_DIN0207_L6.3mm_D2.5mm_P10.16mm_Horizontal
R14, R15, R20, R21, R26, R27, R32, R33, R38, R39, R44, R45, R50, R51, R56, R57, R62, R63, R68, R69, R87, R88, R93, R94: 47k; R_Axial_DIN0207_L6.3mm_D2.5mm_P10.16mm_Horizontal
R70, R72, R76, R78: 150k; R_Axial_DIN0207_L6.3mm_D2.5mm_P10.16mm_Horizontal
R71: 2.2k; R_Axial_DIN0207_L6.3mm_D2.5mm_P10.16mm_Horizontal
R73: 100R; R_Axial_DIN0207_L6.3mm_D2.5mm_P10.16mm_Horizontal
R75: 82k; R_Axial_DIN0207_L6.3mm_D2.5mm_P10.16mm_Horizontal
R77, R81: 12k; R_Axial_DIN0207_L6.3mm_D2.5mm_P10.16mm_Horizontal
R82: 3.9k; R_Axial_DIN0207_L6.3mm_D2.5mm_P10.16mm_Horizontal
RN1, RN2, RN3, RN4: 100k; R_Array_SIP9
RV1, RV2, RV3, RV4, RV5, RV6, RV7, RV8, RV9, RV10, RV11, RV12, RV13, RV14: A10k; Potentiometer_Alpha_RA6020F_Single_Slide
U1, U2, U3, U4, U5, U6, U7, U8: TL074; DIP-14_W7.62mm_Socket_LongPads

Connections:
+12V: C2.2, C6.2, C8.2, C11.2, C13.2, C15.2, C16.1, C19.2, C21.2, D1.1, U1.4, U2.4, U3.4, U4.4, U5.4, U6.4, U7.4, U8.4
-12V: C1.1, C5.1, C7.1, C10.1, C12.1, C14.1, C17.2, C18.1, C20.1, D2.2, U1.11, U2.11, U3.11, U4.11, U5.11, U6.11, U7.11, U8.11
/+12_IN: D1.2, J1.9, J1.10
/-12_IN: D2.1, J1.1, J1.2
/Band pass 1, 2/IN: C9.1, C105.2, R3.1, R10.2, R11.2, R22.2, R23.2, R34.2, R35.2, R46.2, R47.2, R58.2, R59.2, R70.2, R83.2, R84.2, U4.8
/Panel components/BP1PP: J7.4, RV4.3
/Panel components/BP2PP: J7.5, RV5.3
/Panel components/BP3PP: J7.3, RV3.3
/Panel components/BP4PP: J7.6, RV6.3
/Panel components/BP5PP: J7.2, RV2.3
/Panel components/BP6PP: J7.7, RV7.3
/Panel components/BP7PP: J7.1, RV1.3
/Panel components/BP8PP: J7.8, RV8.3
/Panel components/BP9PP: J9.3, RV11.3
/Panel components/BP10PP: J9.4, RV12.3
/Panel components/BP11PP: J9.2, RV10.3
/Panel components/BP12P: J9.5, RV13.3
/Panel components/HPPP: J9.6, RV14.3
/Panel components/LPP: J9.1, RV9.3
ALL: J4.4, R7.1
ALL_P: J12.T, J15.4
BP1P: C33.1, C35.1, J2.4, R20.1, U1.1
BP2P: C34.1, C36.1, J2.5, R21.1, U1.14
BP3P: C49.1, C51.1, J2.3, R32.1, U2.1
BP4P: C50.1, C52.1, J2.6, R33.1, U2.14
BP5P: C65.1, C67.1, J2.2, R44.1, U3.1
BP6P: C66.1, C68.1, J2.7, R45.1, U3.14
BP7P: C81.1, C83.1, J2.1, R56.1, U5.1
BP8P: C82.1, C84.1, J2.8, R57.1, U5.14
BP9P: C126.1, C128.1, J3.3, R93.1, U6.1
BP10P: C127.1, C129.1, J3.4, R94.1, U6.14
BP11P: C97.1, C99.1, J3.2, R68.1, U7.1
BP12P: C98.1, C100.1, J3.5, R69.1, U7.14
EVEN: J4.3, R9.1
EVEN_1: J5.1, RN2.2, RN4.9
EVEN_2: J5.3, RN2.3, RN4.8
EVEN_3: J5.5, RN2.4, RN4.7
EVEN_4: J5.7, RN2.5, RN4.6
EVEN_5: J5.9, RN2.6, RN4.5
EVEN_6: J5.11, RN2.7, RN4.4
EVEN_7: J5.13, RN2.8, RN4.3
EVEN_P: J14.T, J15.3
GND: C1.2, C2.1, C5.2, C6.1, C7.2, C8.1, C10.2, C11.1, C12.2, C13.1, C14.2, C15.1, C16.2, C17.1, C18.2, C19.1, C20.2, C21.1, C108.2, C110.2, C114.2, C116.2, J1.3, J1.4, J1.5, J1.6, J1.7, J1.8, J4.1, J6.1, R12.2, R13.2, R18.2, R19.2, R24.2, R25.2, R30.2, R31.2, R36.2, R37.2, R42.2, R43.2, R48.2, R49.2, R54.2, R55.2, R60.2, R61.2, R66.2, R67.2, R75.2, R81.2, R85.2, R86.2, R91.2, R92.2, U1.3, U1.5, U1.10, U1.12, U2.3, U2.5, U2.10, U2.12, U3.3, U3.5, U3.10, U3.12, U4.3, U4.5, U4.10, U4.12, U5.3, U5.5, U5.10, U5.12, U6.3, U6.5, U6.10, U6.12, U7.3, U7.5, U7.10, U7.12
GND1: J10.S, J11.S, J12.S, J13.S, J14.S, J15.1, J16.1, RV1.1, RV2.1, RV3.1, RV4.1, RV5.1, RV6.1, RV7.1, RV8.1, RV9.1, RV10.1, RV11.1, RV12.1, RV13.1, RV14.1
HIGH_INPUT: C3.2, J6.2
HIGH_INPUT_P: J10.T, J16.2
HPP: C117.1, J3.6
LOW_INPUT: C4.2, J6.3
LOW_INPUT_P: J11.T, J16.3
LPP: J3.1, R82.1
unnamed: C3.1, R1.2
unnamed: C4.1, R2.2
unnamed: C9.2, R1.1, R2.1, R3.2, U4.9
unnamed: C22.1, R7.2, RN2.9, U4.14
unnamed: C22.2, RN1.1, RN2.1, U4.13
unnamed: C23.1, R5.1, R8.2, U4.7
unnamed: C23.2, R5.2, RN3.1, U4.6
unnamed: C24.1, R6.1, R9.2, U4.1
unnamed: C24.2, R6.2, RN4.1, U4.2
unnamed: C25.1, C27.1, R14.1, R16.2, U1.7
unnamed: C25.2, C27.2, C29.2, C30.2, R10.1, R12.1
unnamed: C26.1, C28.1, R15.1, R17.2, U1.8
unnamed: C26.2, C28.2, C31.2, C32.2, R11.1, R13.1
unnamed: C29.1, C30.1, R14.2, U1.6
unnamed: C31.1, C32.1, R15.2, U1.9
unnamed: C33.2, C35.2, C37.2, C38.2, R16.1, R18.1
unnamed: C34.2, C36.2, C39.2, C40.2, R17.1, R19.1
unnamed: C37.1, C38.1, R20.2, U1.2
unnamed: C39.1, C40.1, R21.2, U1.13
unnamed: C41.1, C43.1, R26.1, R28.2, U2.7
unnamed: C41.2, C43.2, C45.2, C46.2, R22.1, R24.1
unnamed: C42.1, C44.1, R27.1, R29.2, U2.8
unnamed: C42.2, C44.2, C47.2, C48.2, R23.1, R25.1
unnamed: C45.1, C46.1, R26.2, U2.6
unnamed: C47.1, C48.1, R27.2, U2.9
unnamed: C49.2, C51.2, C53.2, C54.2, R28.1, R30.1
unnamed: C50.2, C52.2, C55.2, C56.2, R29.1, R31.1
unnamed: C53.1, C54.1, R32.2, U2.2
unnamed: C55.1, C56.1, R33.2, U2.13
unnamed: C57.1, C59.1, R38.1, R40.2, U3.7
unnamed: C57.2, C59.2, C61.2, C62.2, R34.1, R36.1
unnamed: C58.1, C60.1, R39.1, R41.2, U3.8
unnamed: C58.2, C60.2, C63.2, C64.2, R35.1, R37.1
unnamed: C61.1, C62.1, R38.2, U3.6
unnamed: C63.1, C64.1, R39.2, U3.9
unnamed: C65.2, C67.2, C69.2, C70.2, R40.1, R42.1
unnamed: C66.2, C68.2, C71.2, C72.2, R41.1, R43.1
unnamed: C69.1, C70.1, R44.2, U3.2
unnamed: C71.1, C72.1, R45.2, U3.13
unnamed: C73.1, C75.1, R50.1, R52.2, U5.7
unnamed: C73.2, C75.2, C77.2, C78.2, R46.1, R48.1
unnamed: C74.1, C76.1, R51.1, R53.2, U5.8
unnamed: C74.2, C76.2, C79.2, C80.2, R47.1, R49.1
unnamed: C77.1, C78.1, R50.2, U5.6
unnamed: C79.1, C80.1, R51.2, U5.9
unnamed: C81.2, C83.2, C85.2, C86.2, R52.1, R54.1
unnamed: C82.2, C84.2, C87.2, C88.2, R53.1, R55.1
unnamed: C85.1, C86.1, R56.2, U5.2
unnamed: C87.1, C88.1, R57.2, U5.13
unnamed: C89.1, C91.1, R62.1, R64.2, U7.7
unnamed: C89.2, C91.2, C93.2, C94.2, R58.1, R60.1
unnamed: C90.1, C92.1, R63.1, R65.2, U7.8
unnamed: C90.2, C92.2, C95.2, C96.2, R59.1, R61.1
unnamed: C93.1, C94.1, R62.2, U7.6
unnamed: C95.1, C96.1, R63.2, U7.9
unnamed: C98.2, C100.2, C103.2, C104.2, R65.1, R67.1
unnamed: C101.1, C102.1, R68.2, U7.2
unnamed: C97.2, C99.2, C101.2, C102.2, R64.1, R66.1
unnamed: C103.1, C104.1, R69.2, U7.13
unnamed: C105.1, C109.2, R71.2
unnamed: C106.1, C107.1, R76.2, U8.6, U8.7
unnamed: C106.2, C107.2, R70.1, R72.2
unnamed: C108.1, C110.1, R72.1, U8.5
unnamed: C109.1, R74.1, U8.10
unnamed: C111.1, C115.2, R77.2
unnamed: C111.2, R73.1, U8.8, U8.9
unnamed: C112.1, C113.1, R82.2, U8.1, U8.2
unnamed: C112.2, C113.2, R76.1, R78.2
unnamed: C114.1, C116.1, R78.1, U8.3
unnamed: C115.1, R80.1, U8.12
unnamed: C117.2, R79.1, U8.13, U8.14
unnamed: C118.1, C120.1, R87.1, R89.2, U6.7
unnamed: C118.2, C120.2, C122.2, C123.2, R83.1, R85.1
unnamed: C119.1, C121.1, R88.1, R90.2, U6.8
unnamed: C119.2, C121.2, C124.2, C125.2, R84.1, R86.1
unnamed: C122.1, C123.1, R87.2, U6.6
unnamed: C124.1, C125.1, R88.2, U6.9
unnamed: C126.2, C128.2, C130.2, C131.2, R89.1, R91.1
unnamed: C127.2, C129.2, C132.2, C133.2, R90.1, R92.1
unnamed: C130.1, C131.1, R93.2, U6.2
unnamed: C132.1, C133.1, R94.2, U6.13
unnamed: R71.1, R73.2
unnamed: R74.2, R75.1
unnamed: R77.1, R79.2
unnamed: R80.2, R81.1
ODD: J4.2, R8.1
ODD_1: J5.2, RN1.2, RN3.9
ODD_2: J5.4, RN1.3, RN3.8
ODD_3: J5.6, RN1.4, RN3.7
ODD_4: J5.8, RN1.5, RN3.6
ODD_5: J5.10, RN1.6, RN3.5
ODD_6: J5.12, RN1.7, RN3.4
ODD_7: J5.14, RN1.8, RN3.3
ODD_P: J13.T, J15.2
P2_1: J8.14, RV4.2
P2_2: J8.11, RV5.2
P2_3: J8.12, RV3.2
P2_4: J8.9, RV6.2
P2_5: J8.10, RV2.2
P2_6: J8.7, RV7.2
P2_7: J8.8, RV1.2
P2_8: J8.5, RV8.2
P2_9: J8.6, RV11.2
P2_10: J8.3, RV12.2
P2_11: J8.4, RV10.2
P2_12: J8.1, RV13.2
P2_H: J8.2, RV14.2
P2_L: J8.13, RV9.2

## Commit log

2021-05-26 Initial version
    [ysFFB-aux.kicad_pcb, ysFFB-aux.sch]
2021-08-11 Reorganized; new main board design; replaced aux board design
    [bp0102.sch, bp0304.sch, bp0506.sch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]
2021-08-12 Fix socket that looked suspiciously like a header. Fix every last remaining inconsistency.
    [panel.sch, ysFFB.kicad_pcb]
2021-08-19 Revised NPTH scheme
    [ysFFB-panel.kicad_pcb, ysFFB-panel.sch]
2021-08-20 No NPTH specialization
    [ysFFB-panel.kicad_pcb, ysFFB-panel.sch]
2021-08-21 relocate libraries; PCB revisions
2021-08-21 rm project libraries
    [ysFFB-panel-NPTH.drl, ysFFB-panel-PTH.drl]
2021-09-09 Clean up libraries, Schottky footprint update
    [ysFFB.kicad_pcb, ysFFB.sch]
2021-09-15 Tidy C values and symbols
    [bp0102.sch, bp0304.sch, bp0506.sch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]
2021-09-18 Cap vals on PCB, revised panel
    [ysFFB-panel.kicad_pcb, ysFFB.kicad_pcb]
2021-09-23 Pre fab tweaks, new Gerbers, correct alignment and make PCB dimensions symmetric in module
    [panel.sch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]
2021-10-17 Minor sch tweaks, revise README and break out retuning doc
    [panel.sch]
2021-10-17 Fix and document power connection error
    [ysFFB.kicad_pcb, ysFFB.sch]
2021-10-22 Update BOM and README, improve format of bank.py
    [ysFFB.sch]
2021-10-24 Correct Gerbers
    [ysFFB-B_Cu.gbr, ysFFB-B_Mask.gbr, ysFFB-B_Paste.gbr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]
2021-12-24 Current draw
